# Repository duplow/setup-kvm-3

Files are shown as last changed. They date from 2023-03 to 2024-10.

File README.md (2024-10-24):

# setup-kvm-3

**Chaveador KVM** (**K**eyboard **V**ideo **M**ouse) para até 3 PCs/aparelhos diferentes conectados simultaneamente, podendo alternar entre sí.

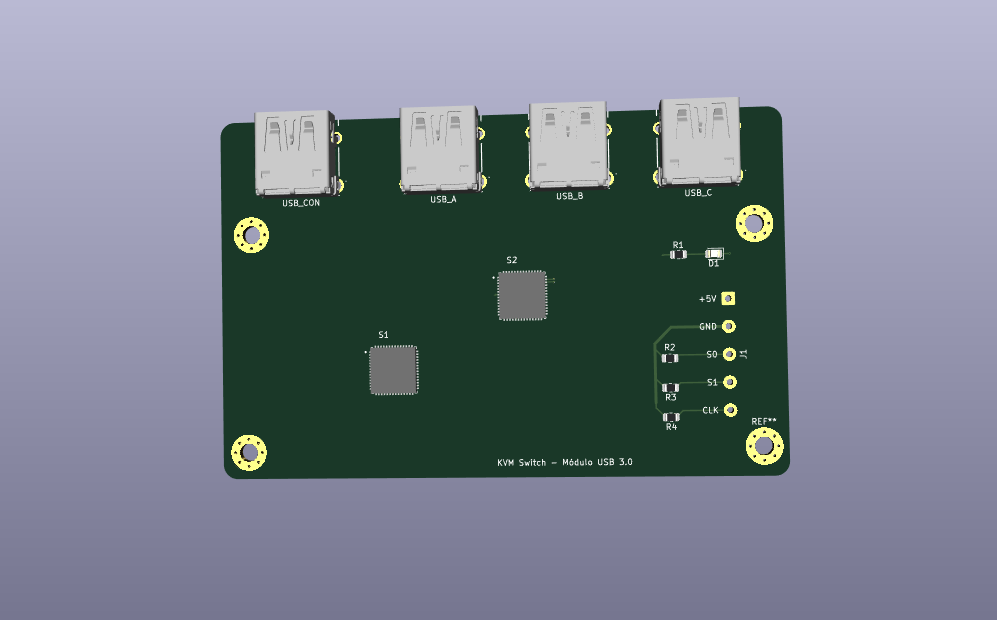
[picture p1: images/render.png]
KVM Switch Render!

_Imagem ilustrativa_

Cada aparelho conectado contará com 3 entradas **HDMI**, 3 entradas **DisplayPort** e 1 entrada **USB 3.0**.

O projeto é montado em cima de um Arduino para fazer o chaveamento entre os aparelhos via teclado, caso opte por um chaveamento apenas via botão fisico o Arduino não será necessário.

O chavemento será feito pelo botão físico no aparelho ou via um teclado USB usando os atalhos:

- `CTRL+SHIFT+NUM+1` para o aparelho número 1
- `CTRL+SHIFT+NUM+2` para o aparelho número 2
- `CTRL+SHIFT+NUM+3` para o aparelho número 3

e assim por diante

---

## Instruções

### Fabricação

 - espessura minima das trilhas (width): 0.2mm
 - espaçamento minimo (min clearance): 0.2mm (usado 0.25m)
 - fotolito: 10.000 DPI

### Módulos

- [Módulo Alimentação](/docs/power-module.md)
- [Módulo Displayport](/docs/displayport-module.md)
- [Módulo USB 3.0 tipo A](/docs/usb-30-module.md)
- [Módulo Controle](/docs/controller-module.md)

### Materiais

Componentes necessários para um KVM de até 3 aparelhos:

- **Arduino** qualquer modelo (opcional)
- 70x Buffers **SN74HC541N** (6 por HDMI, 6 por DisplayPort e 2 por USB)
- 4x Conectores **USB 3.0 DIP** fêmea
- 9x Conectores **HDMI** fêmea [link de venda](https://pt.aliexpress.com/item/1005004321901753.html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)
- 9x Conectores **DisplayPort DIP** fêmea
- 4x Conectores **P2** de áudio e microfone [link de venda](https://pt.aliexpress.com/item/1005004688929020.html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)

> É possível substituir os buffers `SN74HC541N` por multiplexadores `74HC4052`, porém será necessário muitos deles para fazer o mesmo trabalho, para cada `SN74HC541N` será necessário mais ou menos 4 multiplexadores `74HC4052`.

TODO: Colocar o link para o BOM

### Esquemas

Placa USB
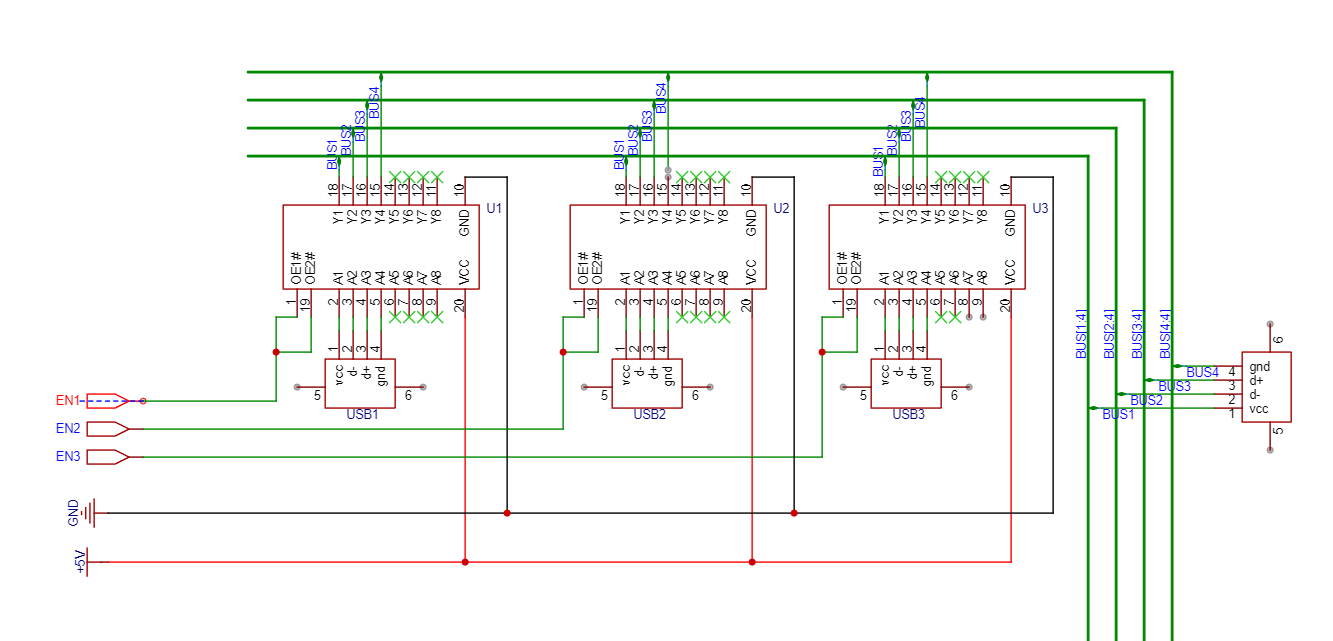
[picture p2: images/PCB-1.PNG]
Placa USB!


### Montagem

Em desenvolvimento

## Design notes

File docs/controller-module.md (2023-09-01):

# Módulo Controlador

Este módulo faz o chaveamento das entradas e saídas e controla os demais módulos.

## Características

- Tipo de conectores: N/A
- Tensão de operação: 3.3V

## Recursos

- Switch por botão físico ✔️
- Switch por I/O ✔️
- Switch por controle remoto (IR) ❌
- Switch por teclado ❌

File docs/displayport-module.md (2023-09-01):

# Módulo de vídeo Displayport

Este módulo faz chaveamento de 3 monitores para 1 usando conectores displayport 1.4+

## Características

- Tipo de conectores: Displayport 1.4+
- Tensão de operação: 3.3V
- Consumo em operação: 60mA
- Corrente máxima na saída: 500mA

## Recursos

- Switch por I/O ✔️
- 4K@30 ✔️
- HDP ❌
- Audio ❌

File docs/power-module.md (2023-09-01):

# Módulo de Alimentação

Este módulo fornece energia para os demais módulos

## Características

- Tipo de conectores: Jack e USB-A
- Tensão de operação: 3.3V e 5V
- Corrente de operação: 500mA a 1A

## Recursos

- Suporta 5V ✔️
- Suporta 3.3V ✔️
- ESD ❌

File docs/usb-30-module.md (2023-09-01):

# Módulo USB 3.0

Este módulo faz o chaveamento de 1 entrada USB para 3 saídas.

> Nota: esse módulo trabalha de forma inversa ao módulo displayport

## Características

- Tipo de conectores: USB 3.0 tipo A
- Tensão de operação: 5V
- Consumo em operação: 60mA
- Corrente máxima na saída: 500mA

## Recursos

- Low-speed ✔️
- High-speed ✔️
- Compatível com USB 3.0 ✔️
- Conector USB tipo C ❌

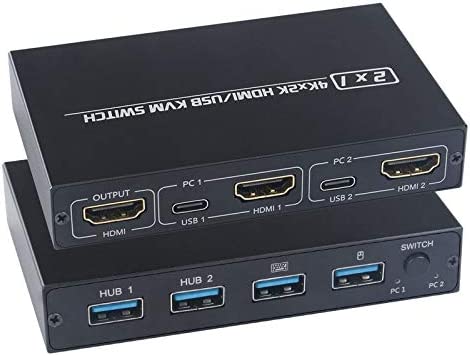
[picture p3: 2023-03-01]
images/kvm-switch-example.jpg

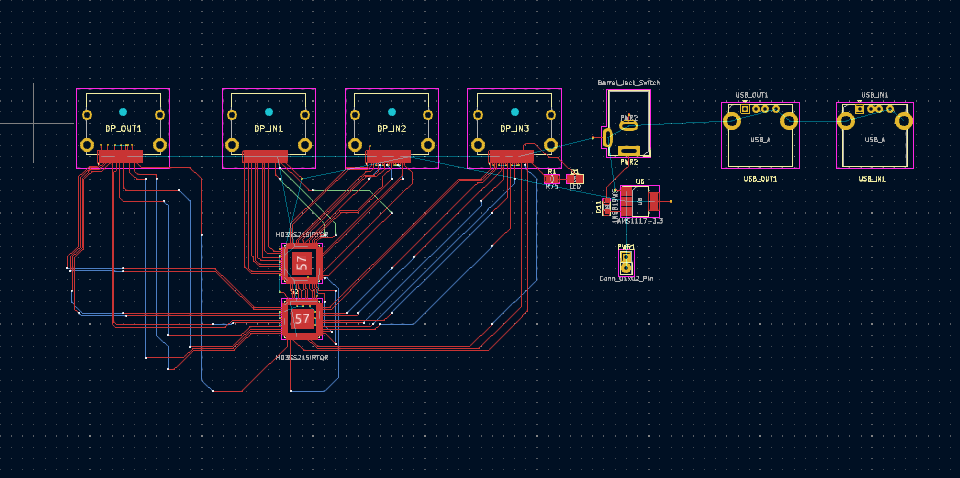
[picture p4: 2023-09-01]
projects/Root/Plots/PCB-Layout.PNG

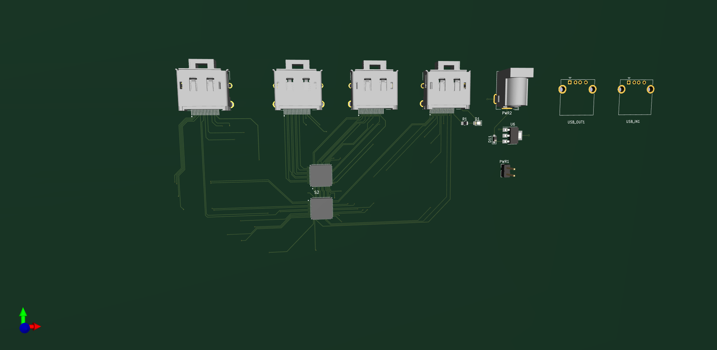
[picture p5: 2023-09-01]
projects/Root/Plots/PCB-View.png

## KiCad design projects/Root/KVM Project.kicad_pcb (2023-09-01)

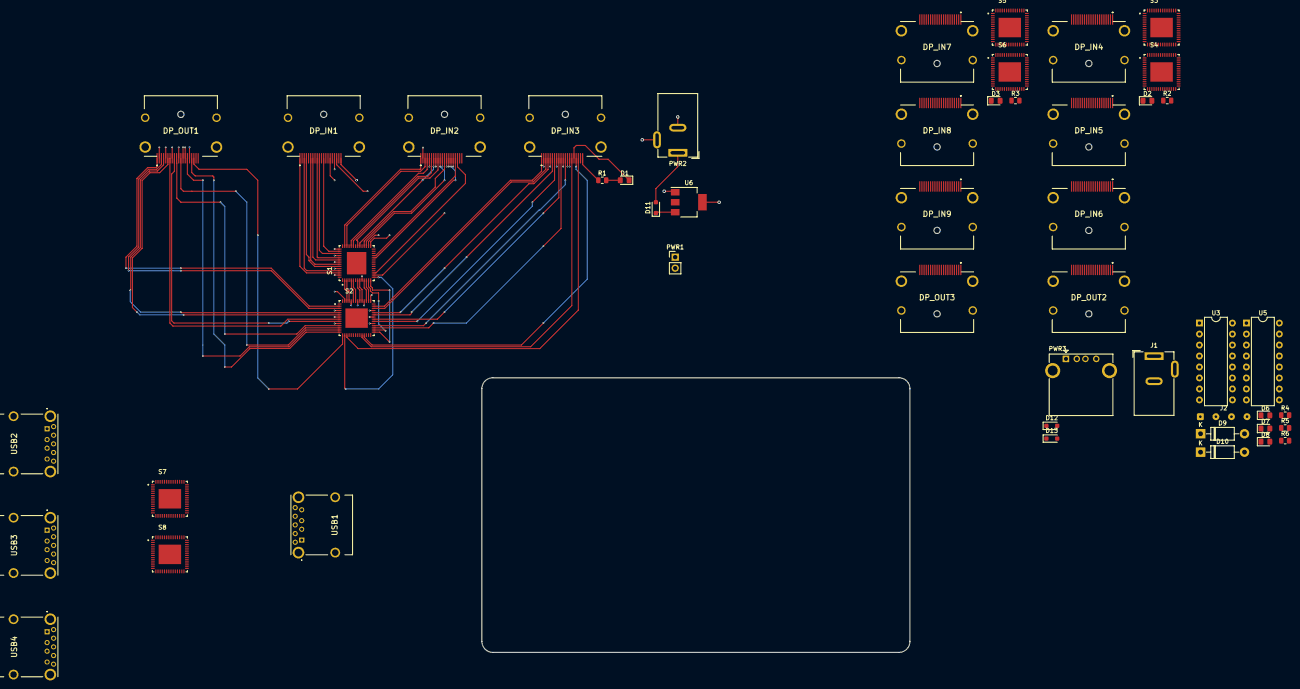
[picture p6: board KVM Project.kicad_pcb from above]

Board: 4 copper layers, 49 parts (0 on the bottom side), 221 nets.

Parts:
D1, D2, D3: LED; LED_0805_2012Metric_Pad1.15x1.40mm_HandSolder
D6: LED1; LED_0805_2012Metric_Pad1.15x1.40mm_HandSolder
D7: LED2; LED_0805_2012Metric_Pad1.15x1.40mm_HandSolder
D8: LED3; LED_0805_2012Metric_Pad1.15x1.40mm_HandSolder
D9, D10: 1N4001; D_DO-41_SOD81_P10.16mm_Horizontal
D11, D12, D13: 1N5819WS; D_SOD-323_HandSoldering
DP_IN1, DP_IN4, DP_IN7: DP_IN1; 472720024
DP_IN2, DP_IN5, DP_IN8: DP_IN2; 472720024
DP_IN3, DP_IN6, DP_IN9: DP_IN3; 472720024
DP_OUT1, DP_OUT2, DP_OUT3: DP_OUT; 472720024
J1: Barrel_Jack_Switch; BarrelJack_Wuerth_6941xx301002
J2: IO pins; SolderWire-0.1sqmm_1x04_P3.6mm_D0.4mm_OD1mm
PWR1: Conn_01x02_Pin; PinHeader_1x02_P2.54mm_Vertical
PWR2: Barrel_Jack_Switch; BarrelJack_Wuerth_6941xx301002
PWR3: USB_A; USB_A_CONNFLY_DS1095-WNR0
R1, R2, R3, R4, R5, R6: R75; R_0805_2012Metric
S1, S2, S3, S4, S5, S6, S7, S8: HD3SS215IRTQR; QFN50P800X800X100-57N
U3: 4017; DIP-16_W7.62mm
U5: 74LS195; DIP-16_W7.62mm
U6: AMS1117-3.3; SOT-223-3_TabPin2
USB1, USB2, USB3, USB4: USB3_Molex_48393-0003

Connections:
+3.3V: DP_IN1.20 (PWR), DP_IN2.20 (PWR), DP_IN4.20 (PWR), DP_IN5.20 (PWR), DP_IN7.20 (PWR), DP_IN8.20 (PWR), DP_OUT1.20 (PWR), DP_OUT2.20 (PWR), DP_OUT3.20 (PWR), J1.1, S1.19 (VDD0), S1.43 (OE), S1.55 (VDD1), S2.19 (VDD0), S2.43 (OE), S2.55 (VDD1), S3.19 (VDD0), S3.43 (OE), S3.55 (VDD1), S4.19 (VDD0), S4.43 (OE), S4.55 (VDD1), S5.19 (VDD0), S5.43 (OE), S5.55 (VDD1), S6.19 (VDD0), S6.43 (OE), S6.55 (VDD1), U3.16 (VDD), U5.16 (VCC), U6.2 (VO)
/Control/LED2_ON: D9.1 (K), R5.1, U3.2 (Q1), U5.4 (P0)
/Control/LED3_ON: D10.1 (K), R6.1, U3.4 (Q2), U5.5 (P1)
/Control/REG_CLK: J2.3, J2.4, U3.14 (CLK), U5.10 (CP)
/Control/RESET: U3.7 (Q3), U3.15 (Reset)
/Control/SI0: D9.2 (A), J2.1
/Control/SI1: D10.2 (A), J2.2
/Display_1/DPIN1_AUX+: DP_IN1.15 (AUX+), S1.30 (AUX_A+)
/Display_1/DPIN1_AUX-: DP_IN1.17 (AUX-), S1.29 (AUX_A-)
/Display_1/DPIN1_D0+: DP_IN1.1 (D0+), S1.54 (D0_A+)
/Display_1/DPIN1_D0-: DP_IN1.3 (D0-), S1.53 (D0_A-)
/Display_1/DPIN1_D1+: DP_IN1.4 (D1+), S1.51 (D1_A+)
/Display_1/DPIN1_D1-: DP_IN1.6 (D1-), S1.50 (D1_A-)
/Display_1/DPIN1_D2+: DP_IN1.7 (D2+), S1.48 (D2_A+)
/Display_1/DPIN1_D2-: DP_IN1.9 (D2-), S1.47 (D2_A-)
/Display_1/DPIN1_D3+: DP_IN1.10 (D3+), S1.45 (D3_A+)
/Display_1/DPIN1_D3-: DP_IN1.12 (D3-), S1.44 (D3_A-)
/Display_1/DPIN1_HPD: DP_IN1.18 (HPD), S1.16 (HPD_A)
/Display_1/DPIN2_AUX+: DP_IN2.15 (AUX+), S1.24 (AUX_B+)
/Display_1/DPIN2_AUX-: DP_IN2.17 (AUX-), S1.25 (AUX_B-)
/Display_1/DPIN2_D0+: DP_IN2.1 (D0+), S1.41 (D0_B+)
/Display_1/DPIN2_D0-: DP_IN2.3 (D0-), S1.40 (D0_B-)
/Display_1/DPIN2_D1+: DP_IN2.4 (D1+), S1.38 (D1_B+)
/Display_1/DPIN2_D1-: DP_IN2.6 (D1-), S1.37 (D1_B-)
/Display_1/DPIN2_D2+: DP_IN2.7 (D2+), S1.35 (D2_B+)
/Display_1/DPIN2_D2-: DP_IN2.9 (D2-), S1.34 (D2_B-)
/Display_1/DPIN2_D3+: DP_IN2.10 (D3+), S1.32 (D3_B+)
/Display_1/DPIN2_D3-: DP_IN2.12 (D3-), S1.31 (D3_B-)
/Display_1/DPIN2_HPD: DP_IN2.18 (HPD), S1.17 (HPD_B)
/Display_1/DPIN3_AUX+: DP_IN3.15 (AUX+), S2.24 (AUX_B+)
/Display_1/DPIN3_AUX-: DP_IN3.17 (AUX-), S2.25 (AUX_B-)
/Display_1/DPIN3_D0+: DP_IN3.1 (D0+), S2.41 (D0_B+)
/Display_1/DPIN3_D0-: DP_IN3.3 (D0-), S2.40 (D0_B-)
/Display_1/DPIN3_D1+: DP_IN3.4 (D1+), S2.38 (D1_B+)
/Display_1/DPIN3_D1-: DP_IN3.6 (D1-), S2.37 (D1_B-)
/Display_1/DPIN3_D2+: DP_IN3.7 (D2+), S2.35 (D2_B+)
/Display_1/DPIN3_D2-: DP_IN3.9 (D2-), S2.34 (D2_B-)
/Display_1/DPIN3_D3+: DP_IN3.10 (D3+), S2.32 (D3_B+)
/Display_1/DPIN3_D3-: DP_IN3.12 (D3-), S2.31 (D3_B-)
/Display_1/DPIN3_GND: D1.1 (K), DP_IN3.16 (GND4)
/Display_1/DPIN3_HPD: DP_IN3.18 (HPD), S2.17 (HPD_B)
/Display_1/DPIN3_PWR: DP_IN3.20 (PWR), R1.1
/Display_1/DPOUT_AUX+: DP_OUT1.15 (AUX+), S2.13 (AUX_C+)
/Display_1/DPOUT_AUX-: DP_OUT1.17 (AUX-), S2.14 (AUX_C-)
/Display_1/DPOUT_D0+: DP_OUT1.1 (D0+), S2.2 (D0_C+)
/Display_1/DPOUT_D0-: DP_OUT1.3 (D0-), S2.3 (D0_C-)
/Display_1/DPOUT_D1+: DP_OUT1.4 (D1+), S2.5 (D1_C+)
/Display_1/DPOUT_D1-: DP_OUT1.6 (D1-), S2.6 (D1_C-)
/Display_1/DPOUT_D2+: DP_OUT1.7 (D2+), S2.8 (D2_C+)
/Display_1/DPOUT_D2-: DP_OUT1.9 (D2-), S2.9 (D2_C-)
/Display_1/DPOUT_D3+: DP_OUT1.10 (D3+), S2.11 (D3_C+)
/Display_1/DPOUT_D3-: DP_OUT1.12 (D3-), S2.12 (D3_C-)
/Display_1/DPOUT_HPD: DP_OUT1.18 (HPD), S2.15 (HPD_C)
/Display_2/DPIN1_AUX+: DP_IN4.15 (AUX+), S3.30 (AUX_A+)
/Display_2/DPIN1_AUX-: DP_IN4.17 (AUX-), S3.29 (AUX_A-)
/Display_2/DPIN1_D0+: DP_IN4.1 (D0+), S3.54 (D0_A+)
/Display_2/DPIN1_D0-: DP_IN4.3 (D0-), S3.53 (D0_A-)
/Display_2/DPIN1_D1+: DP_IN4.4 (D1+), S3.51 (D1_A+)
/Display_2/DPIN1_D1-: DP_IN4.6 (D1-), S3.50 (D1_A-)
/Display_2/DPIN1_D2+: DP_IN4.7 (D2+), S3.48 (D2_A+)
/Display_2/DPIN1_D2-: DP_IN4.9 (D2-), S3.47 (D2_A-)
/Display_2/DPIN1_D3+: DP_IN4.10 (D3+), S3.45 (D3_A+)
/Display_2/DPIN1_D3-: DP_IN4.12 (D3-), S3.44 (D3_A-)
/Display_2/DPIN1_HPD: DP_IN4.18 (HPD), S3.16 (HPD_A)
/Display_2/DPIN2_AUX+: DP_IN5.15 (AUX+), S3.24 (AUX_B+)
/Display_2/DPIN2_AUX-: DP_IN5.17 (AUX-), S3.25 (AUX_B-)
/Display_2/DPIN2_D0+: DP_IN5.1 (D0+), S3.41 (D0_B+)
/Display_2/DPIN2_D0-: DP_IN5.3 (D0-), S3.40 (D0_B-)
/Display_2/DPIN2_D1+: DP_IN5.4 (D1+), S3.38 (D1_B+)
/Display_2/DPIN2_D1-: DP_IN5.6 (D1-), S3.37 (D1_B-)
/Display_2/DPIN2_D2+: DP_IN5.7 (D2+), S3.35 (D2_B+)
/Display_2/DPIN2_D2-: DP_IN5.9 (D2-), S3.34 (D2_B-)
/Display_2/DPIN2_D3+: DP_IN5.10 (D3+), S3.32 (D3_B+)
/Display_2/DPIN2_D3-: DP_IN5.12 (D3-), S3.31 (D3_B-)
/Display_2/DPIN2_HPD: DP_IN5.18 (HPD), S3.17 (HPD_B)
/Display_2/DPIN3_AUX+: DP_IN6.15 (AUX+), S4.24 (AUX_B+)
/Display_2/DPIN3_AUX-: DP_IN6.17 (AUX-), S4.25 (AUX_B-)
/Display_2/DPIN3_D0+: DP_IN6.1 (D0+), S4.41 (D0_B+)
/Display_2/DPIN3_D0-: DP_IN6.3 (D0-), S4.40 (D0_B-)
/Display_2/DPIN3_D1+: DP_IN6.4 (D1+), S4.38 (D1_B+)
/Display_2/DPIN3_D1-: DP_IN6.6 (D1-), S4.37 (D1_B-)
/Display_2/DPIN3_D2+: DP_IN6.7 (D2+), S4.35 (D2_B+)
/Display_2/DPIN3_D2-: DP_IN6.9 (D2-), S4.34 (D2_B-)
/Display_2/DPIN3_D3+: DP_IN6.10 (D3+), S4.32 (D3_B+)
/Display_2/DPIN3_D3-: DP_IN6.12 (D3-), S4.31 (D3_B-)
/Display_2/DPIN3_GND: D2.1 (K), DP_IN6.16 (GND4)
/Display_2/DPIN3_HPD: DP_IN6.18 (HPD), S4.17 (HPD_B)
/Display_2/DPIN3_PWR: DP_IN6.20 (PWR), R2.1
/Display_2/DPOUT_AUX+: DP_OUT2.15 (AUX+), S4.13 (AUX_C+)
/Display_2/DPOUT_AUX-: DP_OUT2.17 (AUX-), S4.14 (AUX_C-)
/Display_2/DPOUT_D0+: DP_OUT2.1 (D0+), S4.2 (D0_C+)
/Display_2/DPOUT_D0-: DP_OUT2.3 (D0-), S4.3 (D0_C-)
/Display_2/DPOUT_D1+: DP_OUT2.4 (D1+), S4.5 (D1_C+)
/Display_2/DPOUT_D1-: DP_OUT2.6 (D1-), S4.6 (D1_C-)
/Display_2/DPOUT_D2+: DP_OUT2.7 (D2+), S4.8 (D2_C+)
/Display_2/DPOUT_D2-: DP_OUT2.9 (D2-), S4.9 (D2_C-)
/Display_2/DPOUT_D3+: DP_OUT2.10 (D3+), S4.11 (D3_C+)
/Display_2/DPOUT_D3-: DP_OUT2.12 (D3-), S4.12 (D3_C-)
/Display_2/DPOUT_HPD: DP_OUT2.18 (HPD), S4.15 (HPD_C)
/Display_3/DPIN1_AUX+: DP_IN7.15 (AUX+), S5.30 (AUX_A+)
/Display_3/DPIN1_AUX-: DP_IN7.17 (AUX-), S5.29 (AUX_A-)
/Display_3/DPIN1_D0+: DP_IN7.1 (D0+), S5.54 (D0_A+)
/Display_3/DPIN1_D0-: DP_IN7.3 (D0-), S5.53 (D0_A-)
/Display_3/DPIN1_D1+: DP_IN7.4 (D1+), S5.51 (D1_A+)
/Display_3/DPIN1_D1-: DP_IN7.6 (D1-), S5.50 (D1_A-)
/Display_3/DPIN1_D2+: DP_IN7.7 (D2+), S5.48 (D2_A+)
/Display_3/DPIN1_D2-: DP_IN7.9 (D2-), S5.47 (D2_A-)
/Display_3/DPIN1_D3+: DP_IN7.10 (D3+), S5.45 (D3_A+)
/Display_3/DPIN1_D3-: DP_IN7.12 (D3-), S5.44 (D3_A-)
/Display_3/DPIN1_HPD: DP_IN7.18 (HPD), S5.16 (HPD_A)
/Display_3/DPIN2_AUX+: DP_IN8.15 (AUX+), S5.24 (AUX_B+)
/Display_3/DPIN2_AUX-: DP_IN8.17 (AUX-), S5.25 (AUX_B-)
/Display_3/DPIN2_D0+: DP_IN8.1 (D0+), S5.41 (D0_B+)
/Display_3/DPIN2_D0-: DP_IN8.3 (D0-), S5.40 (D0_B-)
/Display_3/DPIN2_D1+: DP_IN8.4 (D1+), S5.38 (D1_B+)
/Display_3/DPIN2_D1-: DP_IN8.6 (D1-), S5.37 (D1_B-)
/Display_3/DPIN2_D2+: DP_IN8.7 (D2+), S5.35 (D2_B+)
/Display_3/DPIN2_D2-: DP_IN8.9 (D2-), S5.34 (D2_B-)
/Display_3/DPIN2_D3+: DP_IN8.10 (D3+), S5.32 (D3_B+)
/Display_3/DPIN2_D3-: DP_IN8.12 (D3-), S5.31 (D3_B-)
/Display_3/DPIN2_HPD: DP_IN8.18 (HPD), S5.17 (HPD_B)
/Display_3/DPIN3_AUX+: DP_IN9.15 (AUX+), S6.24 (AUX_B+)
/Display_3/DPIN3_AUX-: DP_IN9.17 (AUX-), S6.25 (AUX_B-)
/Display_3/DPIN3_D0+: DP_IN9.1 (D0+), S6.41 (D0_B+)
/Display_3/DPIN3_D0-: DP_IN9.3 (D0-), S6.40 (D0_B-)
/Display_3/DPIN3_D1+: DP_IN9.4 (D1+), S6.38 (D1_B+)
/Display_3/DPIN3_D1-: DP_IN9.6 (D1-), S6.37 (D1_B-)
/Display_3/DPIN3_D2+: DP_IN9.7 (D2+), S6.35 (D2_B+)
/Display_3/DPIN3_D2-: DP_IN9.9 (D2-), S6.34 (D2_B-)
/Display_3/DPIN3_D3+: DP_IN9.10 (D3+), S6.32 (D3_B+)
/Display_3/DPIN3_D3-: DP_IN9.12 (D3-), S6.31 (D3_B-)
/Display_3/DPIN3_GND: D3.1 (K), DP_IN9.16 (GND4)
/Display_3/DPIN3_HPD: DP_IN9.18 (HPD), S6.17 (HPD_B)
/Display_3/DPIN3_PWR: DP_IN9.20 (PWR), R3.1
/Display_3/DPOUT_AUX+: DP_OUT3.15 (AUX+), S6.13 (AUX_C+)
/Display_3/DPOUT_AUX-: DP_OUT3.17 (AUX-), S6.14 (AUX_C-)
/Display_3/DPOUT_D0+: DP_OUT3.1 (D0+), S6.2 (D0_C+)
/Display_3/DPOUT_D0-: DP_OUT3.3 (D0-), S6.3 (D0_C-)
/Display_3/DPOUT_D1+: DP_OUT3.4 (D1+), S6.5 (D1_C+)
/Display_3/DPOUT_D1-: DP_OUT3.6 (D1-), S6.6 (D1_C-)
/Display_3/DPOUT_D2+: DP_OUT3.7 (D2+), S6.8 (D2_C+)
/Display_3/DPOUT_D2-: DP_OUT3.9 (D2-), S6.9 (D2_C-)
/Display_3/DPOUT_D3+: DP_OUT3.10 (D3+), S6.11 (D3_C+)
/Display_3/DPOUT_D3-: DP_OUT3.12 (D3-), S6.12 (D3_C-)
/Display_3/DPOUT_HPD: DP_OUT3.18 (HPD), S6.15 (HPD_C)
/Power Supply/VCC_IN: D11.1 (K), D12.1 (K), D13.1 (K), U6.3 (VI)
/S0: S1.1 (AUX_SEL), S1.56 (DX_SEL), S3.1 (AUX_SEL), S3.56 (DX_SEL), S5.1 (AUX_SEL), S5.56 (DX_SEL), S8.1 (AUX_SEL), S8.56 (DX_SEL), U5.15 (Q0)
/S1: S2.1 (AUX_SEL), S2.56 (DX_SEL), S4.1 (AUX_SEL), S4.56 (DX_SEL), S6.1 (AUX_SEL), S6.56 (DX_SEL), S7.1 (AUX_SEL), S7.56 (DX_SEL), U5.14 (Q1)
/USB Switch/+5V: S7.19 (VDD0), S7.43 (OE), S7.55 (VDD1), S8.19 (VDD0), S8.43 (OE), S8.55 (VDD1)
/USB Switch/D0+: S7.2 (D0_C+), USB1.3 (D+)
/USB Switch/D0-: S7.3 (D0_C-), USB1.2 (D-)
/USB Switch/D1+: S7.5 (D1_C+), USB1.6 (SSRX+)
/USB Switch/D1-: S7.6 (D1_C-), USB1.5 (SSRX-)
/USB Switch/D2+: S7.8 (D2_C+), USB1.9 (SSTX+)
/USB Switch/D2-: S7.9 (D2_C-), USB1.8 (SSTX-)
/USB Switch/USB_AB_D0+: S7.54 (D0_A+), S8.2 (D0_C+)
/USB Switch/USB_AB_D0-: S7.53 (D0_A-), S8.3 (D0_C-)
/USB Switch/USB_AB_D1+: S7.51 (D1_A+), S8.5 (D1_C+)
/USB Switch/USB_AB_D1-: S7.50 (D1_A-), S8.6 (D1_C-)
/USB Switch/USB_AB_D2+: S7.48 (D2_A+), S8.8 (D2_C+)
/USB Switch/USB_AB_D2-: S7.47 (D2_A-), S8.9 (D2_C-)
/USB Switch/USB_A_D0+: S8.54 (D0_A+), USB2.3 (D+)
/USB Switch/USB_A_D0-: S8.53 (D0_A-), USB2.2 (D-)
/USB Switch/USB_A_D1+: S8.51 (D1_A+), USB2.6 (SSRX+)
/USB Switch/USB_A_D1-: S8.50 (D1_A-), USB2.5 (SSRX-)
/USB Switch/USB_A_D2+: S8.48 (D2_A+), USB2.9 (SSTX+)
/USB Switch/USB_A_D2-: S8.47 (D2_A-), USB2.8 (SSTX-)
/USB Switch/USB_B_D0+: S8.41 (D0_B+), USB3.3 (D+)
/USB Switch/USB_B_D0-: S8.40 (D0_B-), USB3.2 (D-)
/USB Switch/USB_B_D1+: S8.38 (D1_B+), USB3.6 (SSRX+)
/USB Switch/USB_B_D1-: S8.37 (D1_B-), USB3.5 (SSRX-)
/USB Switch/USB_B_D2+: S8.35 (D2_B+), USB3.9 (SSTX+)
/USB Switch/USB_B_D2-: S8.34 (D2_B-), USB3.8 (SSTX-)
/USB Switch/USB_C_D0-: S7.40 (D0_B-), USB4.2 (D-)
/USB Switch/USB_C_D1+: S7.38 (D1_B+), USB4.6 (SSRX+)
/USB Switch/USB_C_D1-: S7.37 (D1_B-), USB4.5 (SSRX-)
/USB Switch/USB_C_D2+: S7.35 (D2_B+), USB4.9 (SSTX+)
/USB Switch/USB_C_D2-: S7.34 (D2_B-), USB4.8 (SSTX-)
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

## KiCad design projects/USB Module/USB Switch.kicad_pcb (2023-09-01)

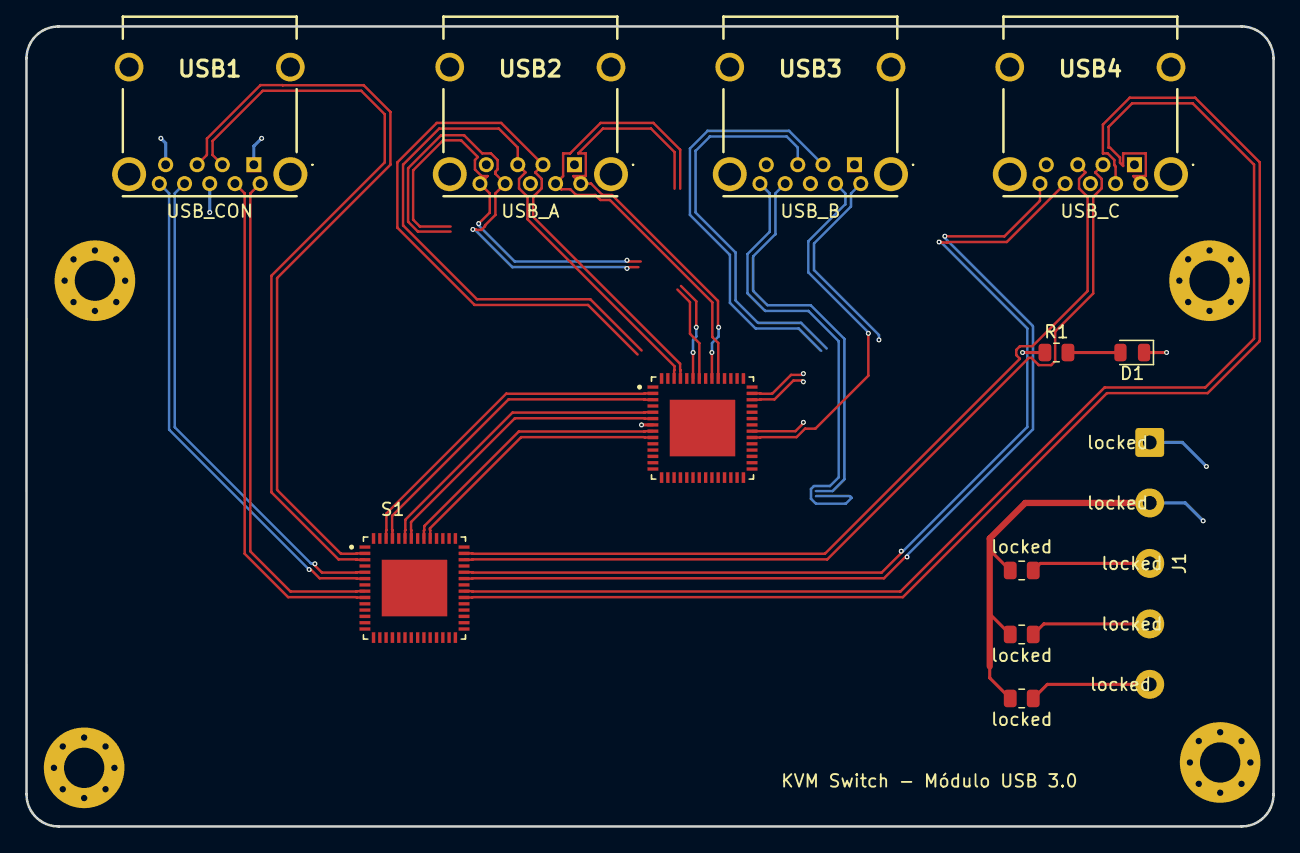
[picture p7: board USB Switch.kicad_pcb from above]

Board: 4 copper layers, 99.0 x 63.5 mm, 12 parts (0 on the bottom side), 38 nets.

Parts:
D1: LED; LED_0805_2012Metric
J1: Conn_01x05_Socket; SolderWire-0.5sqmm_1x05_P4.8mm_D0.9mm_OD2.3mm
R1: 167R; R_0805_2012Metric
S1, S2: HD3SS215IRTQR; QFN50P800X800X100-57N
USB1, USB2, USB3, USB4: USB3_Molex_48393-0003
locked: locked; R_0805_2012Metric
locked#2, locked#3: locked; R_0805_2012Metric

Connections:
/+5V: J1.1, R1.1
/CLOCK: J1.5, locked#2.1
/GND: D1.1 (K), J1.2, locked.2, locked#2.2, locked#3.2
/S0: J1.3, S2.1 (AUX_SEL), S2.56 (DX_SEL), locked#3.1
/S1: J1.4, S1.1 (AUX_SEL), S1.56 (DX_SEL), locked.1
/Switch/+5V: S1.19 (VDD0), S1.43 (OE), S1.55 (VDD1), S2.19 (VDD0), S2.43 (OE), S2.55 (VDD1), USB1.1 (VBUS)
/Switch/D0+: S1.2 (D0_C+), USB1.3 (D+)
/Switch/D0-: S1.3 (D0_C-), USB1.2 (D-)
/Switch/D1+: S1.5 (D1_C+), USB1.6 (SSRX+)
/Switch/D1-: S1.6 (D1_C-), USB1.5 (SSRX-)
/Switch/D2+: S1.8 (D2_C+), USB1.9 (SSTX+)
/Switch/D2-: S1.9 (D2_C-), USB1.8 (SSTX-)
/Switch/USB_AB_D0+: S1.54 (D0_A+), S2.2 (D0_C+)
/Switch/USB_AB_D0-: S1.53 (D0_A-), S2.3 (D0_C-)
/Switch/USB_AB_D1+: S1.51 (D1_A+), S2.5 (D1_C+)
/Switch/USB_AB_D1-: S1.50 (D1_A-), S2.6 (D1_C-)
/Switch/USB_AB_D2+: S1.48 (D2_A+), S2.8 (D2_C+)
/Switch/USB_AB_D2-: S1.47 (D2_A-), S2.9 (D2_C-)
/Switch/USB_A_D0+: S2.54 (D0_A+), USB2.3 (D+)
/Switch/USB_A_D0-: S2.53 (D0_A-), USB2.2 (D-)
/Switch/USB_A_D1+: S2.51 (D1_A+), USB2.6 (SSRX+)
/Switch/USB_A_D1-: S2.50 (D1_A-), USB2.5 (SSRX-)
/Switch/USB_A_D2+: S2.48 (D2_A+), USB2.9 (SSTX+)
/Switch/USB_A_D2-: S2.47 (D2_A-), USB2.8 (SSTX-)
/Switch/USB_B_D0+: S2.41 (D0_B+), USB3.3 (D+)
/Switch/USB_B_D0-: S2.40 (D0_B-), USB3.2 (D-)
/Switch/USB_B_D1+: S2.38 (D1_B+), USB3.6 (SSRX+)
/Switch/USB_B_D1-: S2.37 (D1_B-), USB3.5 (SSRX-)
/Switch/USB_B_D2+: S2.35 (D2_B+), USB3.9 (SSTX+)
/Switch/USB_B_D2-: S2.34 (D2_B-), USB3.8 (SSTX-)
/Switch/USB_C_D0+: S1.41 (D0_B+), USB4.3 (D+)
/Switch/USB_C_D0-: S1.40 (D0_B-), USB4.2 (D-)
/Switch/USB_C_D1+: S1.38 (D1_B+), USB4.6 (SSRX+)
/Switch/USB_C_D1-: S1.37 (D1_B-), USB4.5 (SSRX-)
/Switch/USB_C_D2+: S1.35 (D2_B+), USB4.9 (SSTX+)
/Switch/USB_C_D2-: S1.34 (D2_B-), USB4.8 (SSTX-)
GND: S1.4 (GND0), S1.7 (GND1), S1.10 (GND2), S1.33 (GND3), S1.36 (GND4), S1.39 (GND5), S1.46 (GND6), S1.49 (GND7), S1.52 (GND8), S1.57 (PAD), S2.4 (GND0), S2.7 (GND1), S2.10 (GND2), S2.33 (GND3), S2.36 (GND4), S2.39 (GND5), S2.46 (GND6), S2.49 (GND7), S2.52 (GND8), S2.57 (PAD), USB1.4 (GND), USB1.7 (GND_DRAIN)
unnamed: D1.2 (A), R1.2

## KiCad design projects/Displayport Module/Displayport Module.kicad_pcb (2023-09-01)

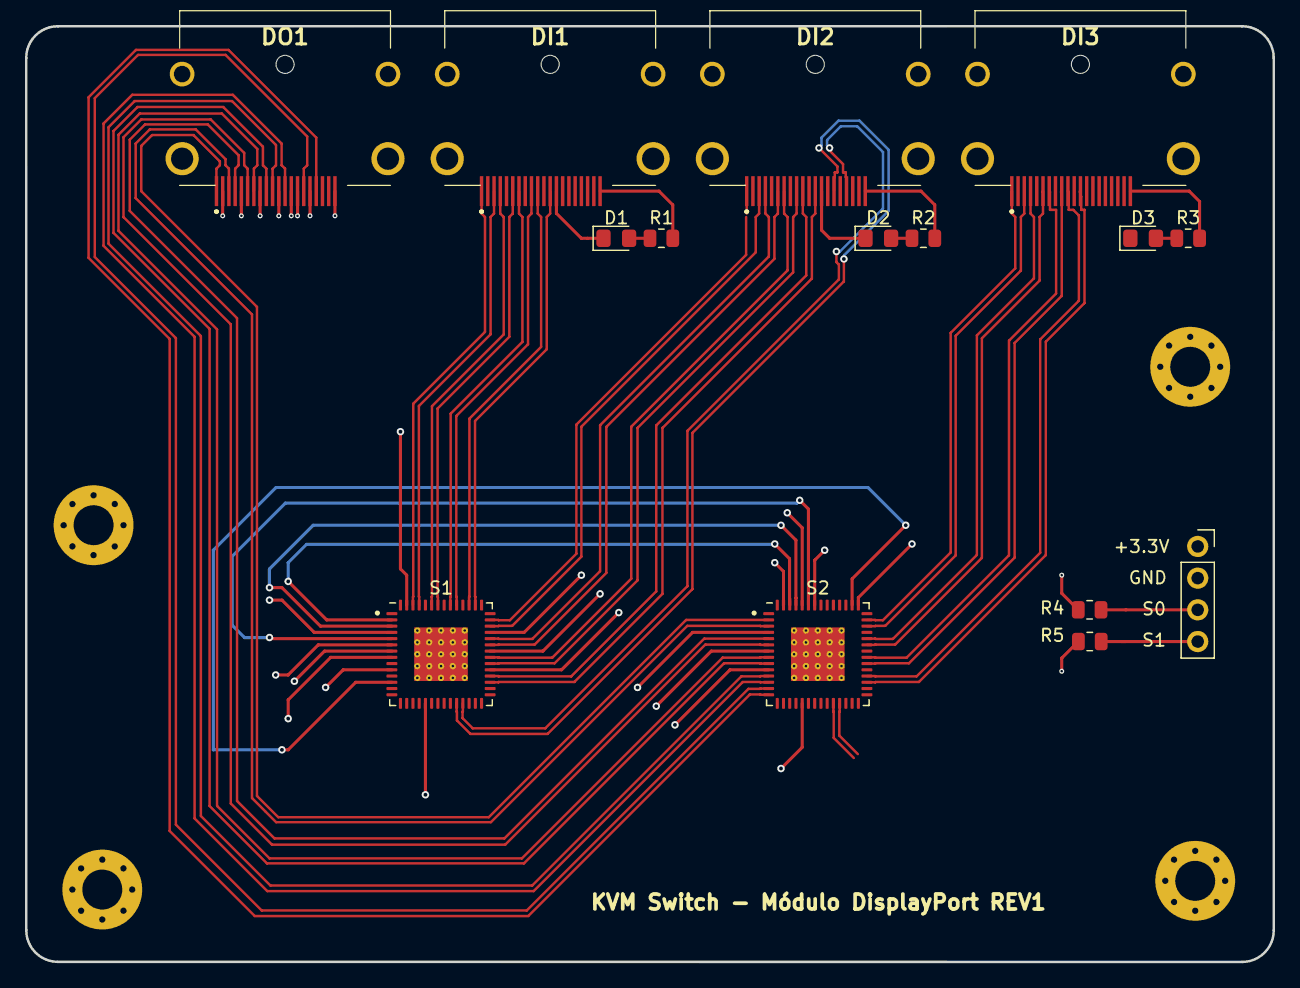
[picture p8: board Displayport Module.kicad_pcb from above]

Board: 4 copper layers, 100.0 x 75.0 mm, 14 parts (0 on the bottom side), 68 nets.

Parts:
D1, D2, D3: LED; LED_0805_2012Metric_Pad1.15x1.40mm_HandSolder
DI1, DI2, DI3: Connector DP IN 47272-0024; 47272-0024
DO1: Connector DP OUT 47272-0024; 47272-0024
R1, R2, R3: R75; R_0805_2012Metric
R4, R5: 10K; R_0805_2012Metric
S1, S2: HD3SS215IRTQR; QFN-56-1EP_8x8mm_P0.5mm_EP4.3x4.3mm_ThermalVias

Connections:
+3.3V: DO1.20 (PWR), S1.19 (VDD0), S1.43 (OE), S1.55 (VDD1), S2.19 (VDD0), S2.43 (OE), S2.55 (VDD1)
/DPIN1_AUX+: DI1.15 (AUX+), S1.30 (AUX_A+)
/DPIN1_AUX-: DI1.17 (AUX-), S1.29 (AUX_A-)
/DPIN1_D0+: DI1.1 (D0+), S1.54 (D0_A+)
/DPIN1_D0-: DI1.3 (D0-), S1.53 (D0_A-)
/DPIN1_D1+: DI1.4 (D1+), S1.51 (D1_A+)
/DPIN1_D1-: DI1.6 (D1-), S1.50 (D1_A-)
/DPIN1_D2+: DI1.7 (D2+), S1.48 (D2_A+)
/DPIN1_D2-: DI1.9 (D2-), S1.47 (D2_A-)
/DPIN1_D3+: DI1.10 (D3+), S1.45 (D3_A+)
/DPIN1_D3-: DI1.12 (D3-), S1.44 (D3_A-)
/DPIN1_GND: D1.1 (K), DI1.13 (CON1)
/DPIN1_HPD: DI1.18 (HPD), S1.16 (HPD_A)
/DPIN1_PWR: DI1.20 (PWR), R1.1
/DPIN2_AUX+: DI2.15 (AUX+), S1.24 (AUX_B+)
/DPIN2_AUX-: DI2.17 (AUX-), S1.25 (AUX_B-)
/DPIN2_D0+: DI2.1 (D0+), S1.41 (D0_B+)
/DPIN2_D0-: DI2.3 (D0-), S1.40 (D0_B-)
/DPIN2_D1+: DI2.4 (D1+), S1.38 (D1_B+)
/DPIN2_D1-: DI2.6 (D1-), S1.37 (D1_B-)
/DPIN2_D2+: DI2.7 (D2+), S1.35 (D2_B+)
/DPIN2_D2-: DI2.9 (D2-), S1.34 (D2_B-)
/DPIN2_D3+: DI2.10 (D3+), S1.32 (D3_B+)
/DPIN2_D3-: DI2.12 (D3-), S1.31 (D3_B-)
/DPIN2_GND: D2.1 (K), DI2.13 (CON1)
/DPIN2_HPD: DI2.18 (HPD), S1.17 (HPD_B)
/DPIN2_PWR: DI2.20 (PWR), R2.1
/DPIN3_AUX+: DI3.15 (AUX+), S2.24 (AUX_B+)
/DPIN3_AUX-: DI3.17 (AUX-), S2.25 (AUX_B-)
/DPIN3_D0+: DI3.1 (D0+), S2.41 (D0_B+)
/DPIN3_D0-: DI3.3 (D0-), S2.40 (D0_B-)
/DPIN3_D1+: DI3.4 (D1+), S2.38 (D1_B+)
/DPIN3_D1-: DI3.6 (D1-), S2.37 (D1_B-)
/DPIN3_D2+: DI3.7 (D2+), S2.35 (D2_B+)
/DPIN3_D2-: DI3.9 (D2-), S2.34 (D2_B-)
/DPIN3_D3+: DI3.10 (D3+), S2.32 (D3_B+)
/DPIN3_D3-: DI3.12 (D3-), S2.31 (D3_B-)
/DPIN3_GND: D3.1 (K), DI3.13 (CON1)
/DPIN3_HPD: DI3.18 (HPD), S2.17 (HPD_B)
/DPIN3_PWR: DI3.20 (PWR), R3.1
/DPOUT_AUX+: DO1.15 (AUX+), S2.13 (AUX_C+)
/DPOUT_AUX-: DO1.17 (AUX-), S2.14 (AUX_C-)
/DPOUT_D0+: DO1.1 (D0+), S2.2 (D0_C+)
/DPOUT_D0-: DO1.3 (D0-), S2.3 (D0_C-)
/DPOUT_D1+: DO1.4 (D1+), S2.5 (D1_C+)
/DPOUT_D1-: DO1.6 (D1-), S2.6 (D1_C-)
/DPOUT_D2+: DO1.7 (D2+), S2.8 (D2_C+)
/DPOUT_D2-: DO1.9 (D2-), S2.9 (D2_C-)
/DPOUT_D3+: DO1.10 (D3+), S2.11 (D3_C+)
/DPOUT_D3-: DO1.12 (D3-), S2.12 (D3_C-)
/DPOUT_HPD: DO1.18 (HPD), S2.15 (HPD_C)
/S0: R4.1, S1.1 (AUX_SEL), S1.56 (DX_SEL)
/S1: R5.1, S2.1 (AUX_SEL), S2.56 (DX_SEL)
GND: DO1.2 (GND0), DO1.5 (GND1), DO1.8 (GND2), DO1.11 (GND3), DO1.13 (CON1), DO1.14 (CON2), DO1.16 (GND4), R4.2, R5.2, S1.4 (GND0), S1.7 (GND1), S1.10 (GND2), S1.33 (GND3), S1.36 (GND4), S1.39 (GND5), S1.46 (GND6), S1.49 (GND7), S1.52 (GND8), S2.4 (GND0), S2.7 (GND1), S2.10 (GND2), S2.33 (GND3), S2.36 (GND4), S2.39 (GND5), S2.46 (GND6), S2.49 (GND7), S2.52 (GND8)
unnamed: D1.2 (A), R1.2
unnamed: D2.2 (A), R2.2
unnamed: D3.2 (A), R3.2
unnamed: S1.13 (AUX_C+), S2.30 (AUX_A+)
unnamed: S1.14 (AUX_C-), S2.29 (AUX_A-)
unnamed: S1.2 (D0_C+), S2.54 (D0_A+)
unnamed: S1.3 (D0_C-), S2.53 (D0_A-)
unnamed: S1.5 (D1_C+), S2.51 (D1_A+)
unnamed: S1.6 (D1_C-), S2.50 (D1_A-)
unnamed: S1.8 (D2_C+), S2.48 (D2_A+)
unnamed: S1.9 (D2_C-), S2.47 (D2_A-)
unnamed: S1.11 (D3_C+), S2.45 (D3_A+)
unnamed: S1.12 (D3_C-), S2.44 (D3_A-)
unnamed: S1.15 (HPD_C), S2.16 (HPD_A)

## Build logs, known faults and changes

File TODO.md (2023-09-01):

# To dos

[] - Colocar kicad no pipeline do projeto: https://hub.docker.com/r/kicad/kicad

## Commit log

2023-09-01 Add projects
    [Backup.kicad_sch, Channel.kicad_sch, Control.kicad_sch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]
2023-09-01 Melhorias no módulo controlador
    [Backup.kicad_sch, Channel.kicad_sch, Control.kicad_sch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]
